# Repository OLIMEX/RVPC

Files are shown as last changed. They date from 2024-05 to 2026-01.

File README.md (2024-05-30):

# RVPC
The EURO 1.00 Risc-V personal computer with VGA and Keyboard and Woz like monitor. The purpose of this project is to make educational platform which people can use to learn RISCV assembler and experiment like in the old days in 1980s :)

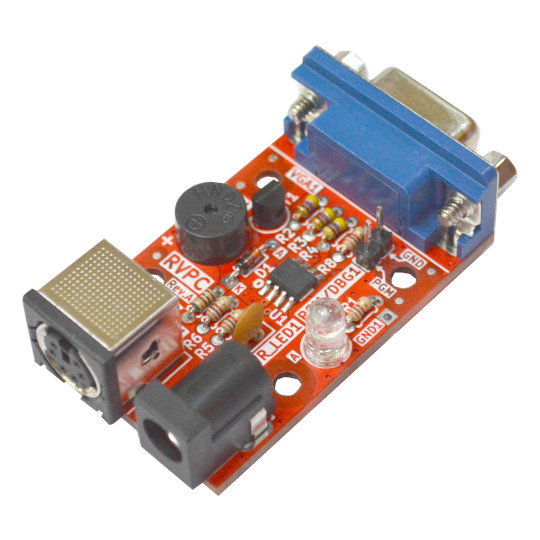
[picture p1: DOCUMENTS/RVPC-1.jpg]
RVPC-1


https://www.olimex.com/Products/Retro-Computers/RVPC/open-source-hardware

## Licensee
* Hardware is released under CERN Open Hardware Licence Version 2 - Strongly Reciprocal
* Software is released under GPL V3 Licensee
* Documentation is released under CC BY-SA 4.0

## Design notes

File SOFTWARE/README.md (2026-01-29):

# PlatformIO
The PlatformIO flder contains demo project which drive the beeper,
You can open and upload it and you will hear sound.

# Tools
The rvpc folder contains all the tools needed to program an ESP32-S2-DevKitLiPo-USB to act as a programmer, and minichlink, which uses the ESP32-S2 to program CH32V003.
Follow the instructions in the user manual.

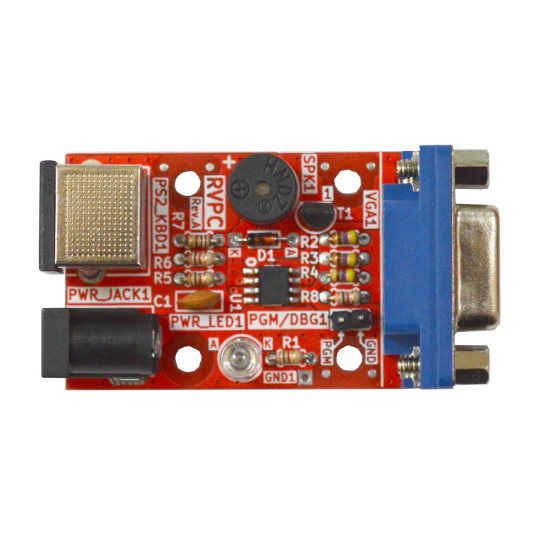
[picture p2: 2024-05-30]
DOCUMENTS/RVPC-2.jpg

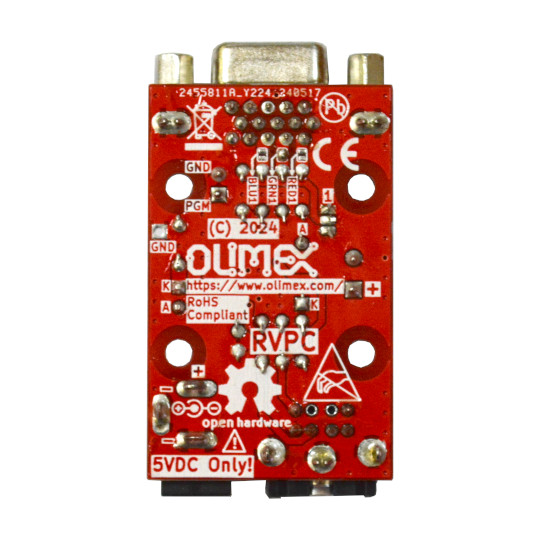
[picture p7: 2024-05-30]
DOCUMENTS/RVPC-3.jpg

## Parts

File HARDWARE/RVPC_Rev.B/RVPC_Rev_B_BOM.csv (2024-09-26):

Quantity | Value | Footprint | Reference
1 | 100nF/25V/2010 | C2010 | C1
1 | 1N4148/DO35 | DO35_1K_2A | D1
1 | HN1x2 | HN1x2 | PGM/DBG1
1 | MDR6_MINI-DIN | PS2_MDR6_MINI-DIN | PS2_KBD1
1 | PWRJ-2mm(YDJ-1134) | PWRJ-2mm(YDJ-1136) | PWR_JACK1
1 | LED/PTH/5MM/RED | LED-5mm-PTH-KA | PWR_LED1
4 | 2k/1/8W | R_0.125W_PTH | R1, R5, R6, R8
3 | 470R/1/8W | R_0.125W_PTH | R2, R3, R4
1 | 100R/1/8W | R_0.125W_PTH | R7
1 | Speaker_QMB-09B-03(1.5-5.0V_2.7kHz_F9.0mm*H5.5mm) | Speaker_QMB-09B-03_1-Plus_2-Minus | SPK1
1 | 2N3904 | TO-92_PTH | T1
1 | CH32V003J4M6(SOP8) | SOIC-8_150mil | U1
1 | HDR15-3.08-14.5T/VGA15/14.5mm | VGA15-F(HDR15-3.08-14.5T)_DrillSlot | VGA1

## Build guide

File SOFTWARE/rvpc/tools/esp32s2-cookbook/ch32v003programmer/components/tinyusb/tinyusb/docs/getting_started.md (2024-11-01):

# Getting Started #

## Add TinyUSB to your project

It is relatively simple to incorporate tinyusb to your (existing) project

- Copy or `git submodule` this repo into your project in a subfolder. Let's say it is *your_project/tinyusb*
- Add all the .c in the `tinyusb/src` folder to your project
- Add *your_project/tinyusb/src* to your include path. Also make sure your current include path also contains the configuration file tusb_config.h.
- Make sure all required macros are all defined properly in tusb_config.h (configure file in demo application is sufficient, but you need to add a few more such as CFG_TUSB_MCU, CFG_TUSB_OS since they are passed by IDE/compiler to maintain a unique configure for all boards).
- If you use the device stack, make sure you have created/modified usb descriptors for your own need. Ultimately you need to implement all **tud_descriptor_** callbacks for the stack to work.
- Add tusb_init() call to your reset initialization code.
- Call `tud_int_handler()` (device) and/or `tuh_int_handler()` (host) in your USB IRQ Handler
- Implement all enabled classes's callbacks.
- If you don't use any RTOSes at all, you need to continuously and/or periodically call tud_task()/tuh_task() function. All of the callbacks and functionality are handled and invoked within the call of that task runner.

~~~{.c}
int main(void)
{
  your_init_code();
  tusb_init(); // initialize tinyusb stack

  while(1) // the mainloop
  {
    your_application_code();

    tud_task(); // device task
    tuh_task(); // host task
  }
}
~~~

## Examples

For your convenience, TinyUSB contains a handful of examples for both host and device with/without RTOS to quickly test the functionality as well as demonstrate how API() should be used. Most examples will work on most of [the supported Boards](boards.md). Firstly we need to `git clone` if not already

```
$ git clone https://github.com/hathach/tinyusb tinyusb
$ cd tinyusb
```

Some TinyUSB examples also requires external submodule libraries in `/lib` such as FreeRTOS, Lightweight IP to build. Run following command to fetch them 

```
$ git submodule update --init lib
```

In addition, MCU driver submodule is also needed to provide low-level MCU peripheral's driver. Luckily, it will be fetched if needed when you run the `make` to build your board.

Note: some examples especially those that uses Vendor class (e.g webUSB) may requires udev permission on Linux (and/or macOS) to access usb device. It depends on your OS distro, typically copy `/examples/device/99-tinyusb.rules` file to /etc/udev/rules.d/ then run `sudo udevadm control --reload-rules && sudo udevadm trigger` is good enough.

### Build

To build example, first change directory to an example folder. 

```
$ cd examples/device/cdc_msc
```

Then compile with `make BOARD=[board_name] all`, for example

```
$ make BOARD=feather_nrf52840_express all
```

Note: `BOARD` can be found as directory name in `hw/bsp`, either in its family/boards or directly under bsp (no family).

#### Port Selection

If a board has several ports, one port is chosen by default in the individual board.mk file. Use option `PORT=x` To choose another port. For example to select the HS port of a STM32F746Disco board, use:

```
$ make BOARD=stm32f746disco PORT=1 all
```

#### Port Speed

A MCU can support multiple operational speed. By default, the example build system will use the fastest supported on the board. Use option `SPEED=full/high` e.g To force F723 operate at full instead of default high speed

```
$ make BOARD=stm32f746disco SPEED=full all
```

### Debug

To compile for debugging add `DEBUG=1`, for example

```
$ make BOARD=feather_nrf52840_express DEBUG=1 all
```

#### Log

Should you have an issue running example and/or submitting an bug report. You could enable TinyUSB built-in debug logging with optional `LOG=`. LOG=1 will only print out error message, LOG=2 print more information with on-going events. LOG=3 or higher is not used yet. 

```
$ make BOARD=feather_nrf52840_express LOG=2 all
```

#### Logger

By default log message is printed via on-board UART which is slow and take lots of CPU time comparing to USB speed. If your board support on-board/external debugger, it would be more efficient to use it for logging. There are 2 protocols: 

- `LOGGER=rtt`: use [Segger RTT protocol](https://www.segger.com/products/debug-probes/j-link/technology/about-real-time-transfer/)   
  - Cons: requires jlink as the debugger.
  - Pros: work with most if not all MCUs
  - Software viewer is JLink RTT Viewer/Client/Logger which is bundled with JLink driver package.
- `LOGGER=swo`: Use dedicated SWO pin of ARM Cortex SWD debug header.
  - Cons: only work with ARM Cortex MCUs minus M0
  - Pros: should be compatible with more debugger that support SWO.
  - Software viewer should be provided along with your debugger driver.

```
$ make BOARD=feather_nrf52840_express LOG=2 LOGGER=rtt all
$ make BOARD=feather_nrf52840_express LOG=2 LOGGER=swo all
```

### Flash

`flash` target will use the default on-board debugger (jlink/cmsisdap/stlink/dfu) to flash the binary, please install those support software in advance. Some board use bootloader/DFU via serial which is required to pass to make command

```
$ make BOARD=feather_nrf52840_express flash
$ make SERIAL=/dev/ttyACM0 BOARD=feather_nrf52840_express flash
```

Since jlink can be used with most of the boards, there is also `flash-jlink` target for your convenience.

```
$ make BOARD=feather_nrf52840_express flash-jlink
```

Some board use uf2 bootloader for drag & drop in to mass storage device, uf2 can be generated with `uf2` target

```
$ make BOARD=feather_nrf52840_express all uf2
```

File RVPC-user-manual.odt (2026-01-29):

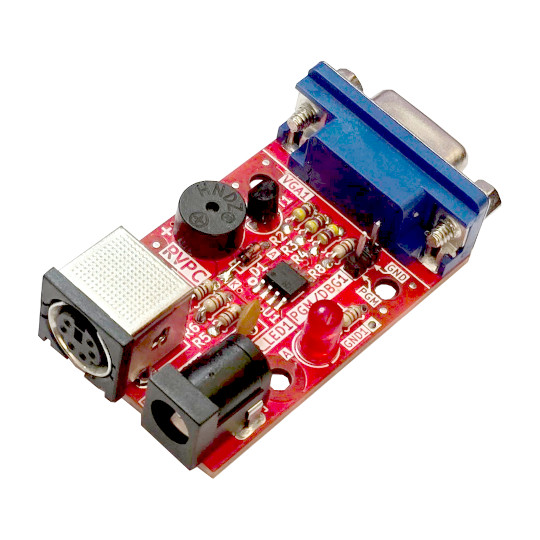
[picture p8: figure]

RVPC

User Manual

Document v1.3 Nov 2024

www. (http://www.olimex.com/)o (http://www.olimex.com/)limex.com (http://www.olimex.com/)

# What is RVPC?

RVPC is an attempt to produce a very low-cost EURO 1.00 educational computer with RISC-V processor which has everything one complete computer has: keyboard input, VGA display output, and audio output.

The idea of RVPC was born from this TuxCon 2024 talk https://youtu.be/YlYE9a7zsqY.

The goal set was:

1. Easy to solder DIY kit;
2. Complete all in one RISC-V computer with bare minimum Woz like monitor which will allow you to learn the RISC-V instructions by poking, peeking and disassembling the memory
3. Price of EUR 1.00!

Here is the result:

CH32V003 in SO8 package – for easy soldering was chosen. It has just 6 GPIOs:

- PS2 takes two GPIOs

- VGA takes three GPIOs – Vsync, Hsync and RGB

- Audio buzzer is connected to the last GPIO

All done using beginner-friendly PTH components!

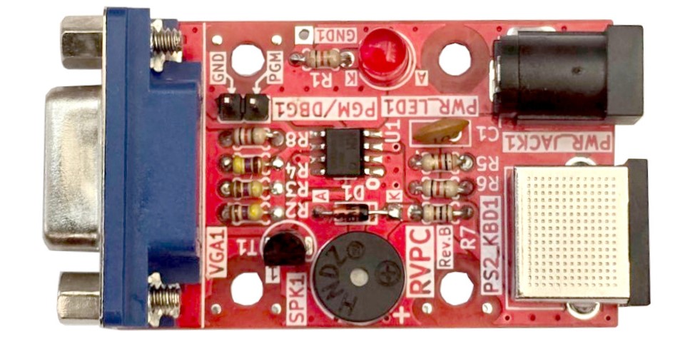
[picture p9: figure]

## Order codes for RVPC and accessories:

RVPC (https://www.olimex.com/Products/Retro-Computers/RVPC/open-source-hardware) Do It Yourself soldering kit

SY0605E (https://www.olimex.com/Products/Power/SY0605E-CHINA/) 5V power supply adapter

PS2-KEYBOARD (https://www.olimex.com/Products/Retro-Computers/PS2-KEYBOARD/) PS2 keyboard

E (https://www.olimex.com/Products/IoT/ESP32-S2/ESP32-S2-DevKit-Lipo-USB/open-source-hardware)SP32-S2-DevKitLiPo-USB (https://www.olimex.com/Products/IoT/ESP32-S2/ESP32-S2-DevKit-Lipo-USB/open-source-hardware) ESP32-S2 development board which can be used as CH32V003

programmer

USB-CABLE-A-MICRO-1.8M (https://www.olimex.com/Products/Components/Cables/USB-CABLE-A-MICRO-1.8M/) USB cable for the programmer

# HARDWARE

## RVPC layout:


PS2 keyboard connector

Buzzer

VGA display

+5V power

jack

Power supply LED indicator

CH32V003 programming

## RVPC schematic:

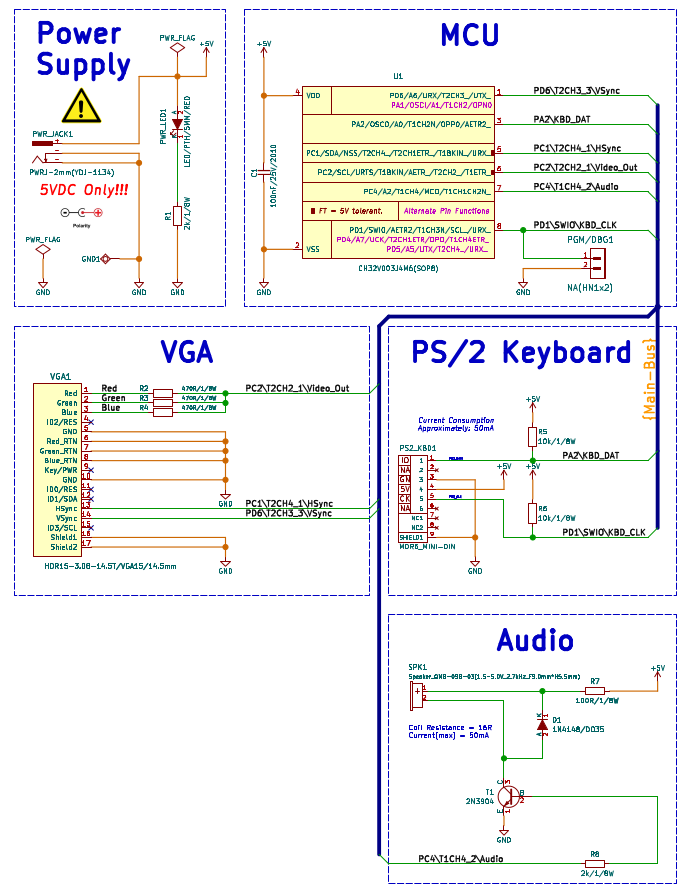
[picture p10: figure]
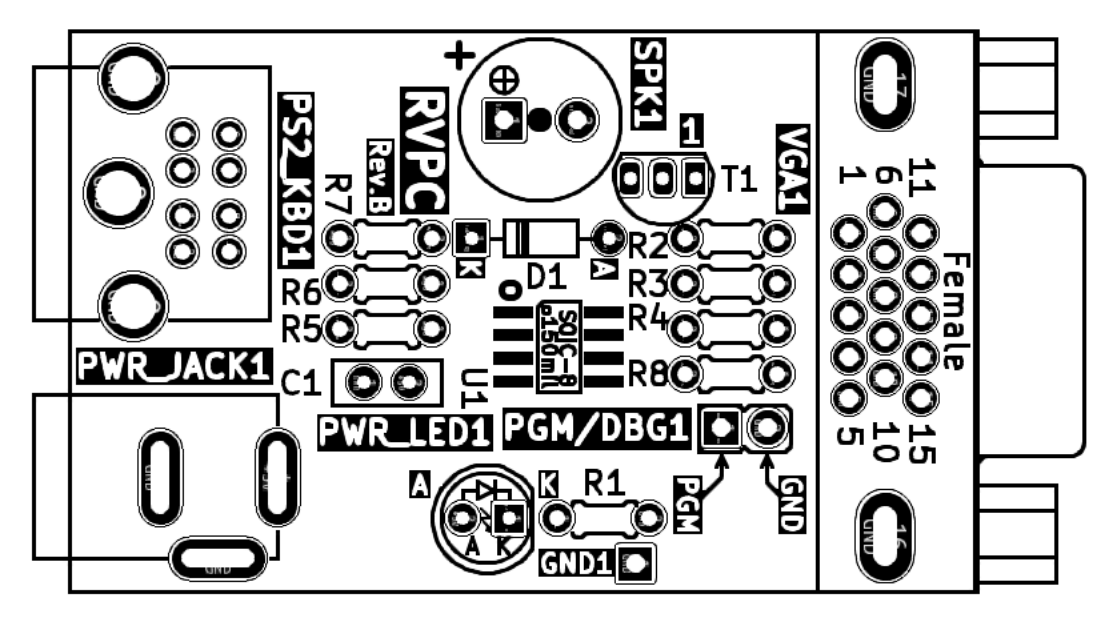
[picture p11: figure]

## RPVC assembly cheat sheet:

After assembly remember to close jumper GRN1 (solder together the pads of GRN1) to enable the green VGA signal.

## Necessary tools:

Wire Cutters: we recommend PGC-TR25 (https://www.olimex.com/Products/Tools/HandTools/PGC-TR25/) these are sharp and light

Tweezers: we recommend PGC-00SA (https://www.olimex.com/Products/Tools/HandTools/PGC-00SA/)

Soldering iron: CHN-SLD802 (https://www.olimex.com/Products/Tools/Soldering/CHN-SLD802/) is budged solution, SLD-FAST-75W (https://www.olimex.com/Products/Tools/Soldering/SLD-FAST-75W/) is professional solution

Soldering wire: we recommend Solder-Wire-SAC0307-0-8 (https://www.olimex.com/Products/Components/Soldering/Solder-Wire-SAC0307-0-8/)

## General tips for soldering:

1. Switch on the soldering iron, setup the working temperature to 350 C. Wait until the soldering iron reaches the temperature – there is a LED indicator which will pulse when the temperature is reached;

2. Before soldering, clean the soldering tip with wet sponge from the black residues;

3. Never touch the heated soldering tip or body with bare hands;

4. Be careful to not touch surrounding objects with the soldering iron heated body or tip (cables, table, cloths, etc);

5. Do not leave the soldering iron unattended;

6. Place the electronic component on its place, watch out if there is polarity or orientation;

7. Touch the component pad with the soldering tip which you want to solder and wait 3-4 seconds to heat up;

8. Feed a little from the soldering wire between the soldering tip and the pad until the component lead is flooded with tin and it’s shinny and glossy;

9. If the soldering is not shinny but dull please re-solder with colophon.

# SOFTWARE:

Below is our setup under Linux:

## Install – packages

$ apt-get install build-essential libnewlib-dev gcc-riscv64-unknown-elf libusb-1.0-0-dev libudev-dev gdb-multiarch

## Install – Visual Studio Code

Described here: https://code.visualstudio.com/docs/setup/linux

## Install – Platform IO

Described here: https://platformio.org/install/ide?install=vscode

## Install – CH32V-Platform

https://github.com/Community-PIO-CH32V/ch32-pio-projects?tab=readme-ov-file#installing-the-ch32v-platform

by default the platformio generates only .elf file, to build firmware.bin and firmware.elf select

> PlatformIO > PROJECT TASKS > Default > Advanced > Verbose build

Sample Beeper project is in RVPC repository.

## Prepare the CH32V003 programmer

ESP32-S2-DevKitLiPo-USB (https://www.olimex.com/Products/IoT/ESP32-S2/ESP32-S2-DevKit-Lipo-USB/open-source-hardware) can be used as programmer.

The repo with all files required to prepare the ESP32-S2 board as programmer is here (https://github.com/OLIMEX/RVPC/tree/main/SOFTWARE) – after you have the resources the algorithm to prepare the programmer is:

1. Press and hold the Boot button and connect the USB cable, the yellow LED will stay ON

check with

$ ls /dev/ttyA*

which is the ttyACM it’s usually 0 or 1

execute this command:

$ python3 ./rvpc/esptool/esptool.py -p /dev/ttyACM0 -b 460800 --before=no_reset --after=no_reset write_flash --flash_mode dio --flash_freq 80m --flash_size 4MB 0x1000 ./rvpc/esp32s2/bootloader.bin 0x10000 ./rvpc/esp32s2/usb_sandbox.bin 0x8000 ./rvpc/esp32s2/partition-table.bin

check if the programmer is already OK with

$ dmesg

you have to see this message:

hid-generic 0003:303A:4004.0015: input,hidraw5: USB HID v1.11 Gamepad [CNLohr ESP32-S2 CH32V003Programmer] on usb-0000:00:14.0-2/input0

which means the ESP32-S2-DevKitLipo-USB now acts as a programmer and can be used with the demo project above from PlatformIO, but first you have to enable it with:

$ sudo cp ./rvpc/tools/ch32v003fun/minichlink/99-minichlink.rules /etc/udev/rules.d/

$ sudo udevadm control --reload-rules && sudo udevadm trigger

Now you can use GPIO6 and GND to connect to RVPC programming connector PGM-GND

Now CH32V003 flashing will work directly from PlatformIO.

If you want to use command line this is the command:

./rvpc/tools/ch32v003fun/minichlink/minichlink -w ./firmware.bin 0x08000000

Notice that if you wish to use the command line programming you’d need to build the minichlink, install these libraries:

sudo apt-get install libudev-dev libusb-1.0-0-dev

then navigate to:

\rvpc\tools\ch32v003fun\minichlink and type make

## Using Raspberry Pi Pico as a programmer

Raspberry Pi Pico can be used as a programmer.

The programmer firmware is located here: https://github.com/aappleby/picorvd. Make sure you install the dependencies, especially GDB as you’ll need it for uploading the RVPC firmware later.

You can either build it yourself, or use a precompiled binary from their CI. The prebuilt binaries can be found in the Actions tab on the repository, selecting the most recent commit and scrolling to the bottom of the page where the Artifacts section is. There should be a single artifact named PicoRVD.uf2, which is the firmware build. If the downloaded file is a ZIP, make sure to unzip the firmware and discard the ZIP file.

Get your RPi Pico, hold down the BOOTSEL button and plug the USB cable into your computer. A new USB mass storage device should appear, copy the PicoRVD firmware file into it and wait for a moment. You don’t need to safely eject/remove it, since it will disconnect itself as soon as it receives the firmware file. It will then immediately boot the PicoRVD firmware and the Pico will be ready for flashing your RVPC.

RVPC firmware uploading is done by the Remote debugging feature of GDB. In order to automate it, you can use the following shell script:

#!/bin/bash

set -e

if [ -z "${1}" ]
then
echo 'usage: '"${0}" path/to/firmware.elf >&2
exit 1
fi

gdb-multiarch -ex 'target extended-remote /dev/ttyACM0' -ex 'load' -ex 'detach' -ex 'quit' "${1}"

To upload a new RVPC firmware, you need the .elf file, not the .bin file as GDB does not have enough information how to upload it. Before uploading a new firmware, restart your RVPC by power cycling it, then power-cycle your Pico and in case it appears as mass storage device, upload the PicoRVD firmware again. Then use the shell script, adjusting the /dev/ttyACM0 port according to the actual serial port name (you can find it in dmesg). After successfully uploading a new RVPC firmware, you need to power-cycle the RVPC, in order to start the program.

## Create project:

If you create a new project to enable the ESP32-S2 programmer you should edit platformio.ini and add this line

upload_protocol = minichlink

This is not needed for demo projects, since it’s already added to the demo projects at our GitHub.

## RVPC monitor demo RVMON (default)

The chip of RVPC comes programmed with this RVPC monitor demo. All demos can be found here:

https://github.com/OLIMEX/RVPC/tree/main/SOFTWARE

This is WOZ-like monitor which allow you to display memory, write to memory and execute code.

The list of all commands are displayed with “?”

## Towers of Hanoi demo

This is original game created by Curtis Whitley who wrote the VGA display code for RVPC.

## Towers of Hanoi Interactive demo

This is modified version which uses the keyboard so user can tell which disk to which tower go.

## TETRIS demo

This is the very popular game made for RVPC.

# Revision History

Revision 1.0 June 2024

Revision 1.1 September 2024

Revision 1.2 October 2024 add assembly instructions

Revision 1.3 November 2024 improved instructions

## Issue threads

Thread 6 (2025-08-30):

No success to get PS/2 Keyboards working

RoSchmi, 2025-08-30:
Thanks for this amazing project.
I soldered the board and get the expected screen output on my monitor. However I had no success to enter commands to the monitor. I tried different PS/2 keyboards and USB-Keyboards with PS/2 adapter with no success. The only reaction is some disturbance of the screen picture when I type a character. Are there any known issues or measures that have to be taken?
Kind regards
Roland

RoSchmi, 2025-08-30:
Turned out to be a soldering problem. It's working now.

Closed 2025-08-31.

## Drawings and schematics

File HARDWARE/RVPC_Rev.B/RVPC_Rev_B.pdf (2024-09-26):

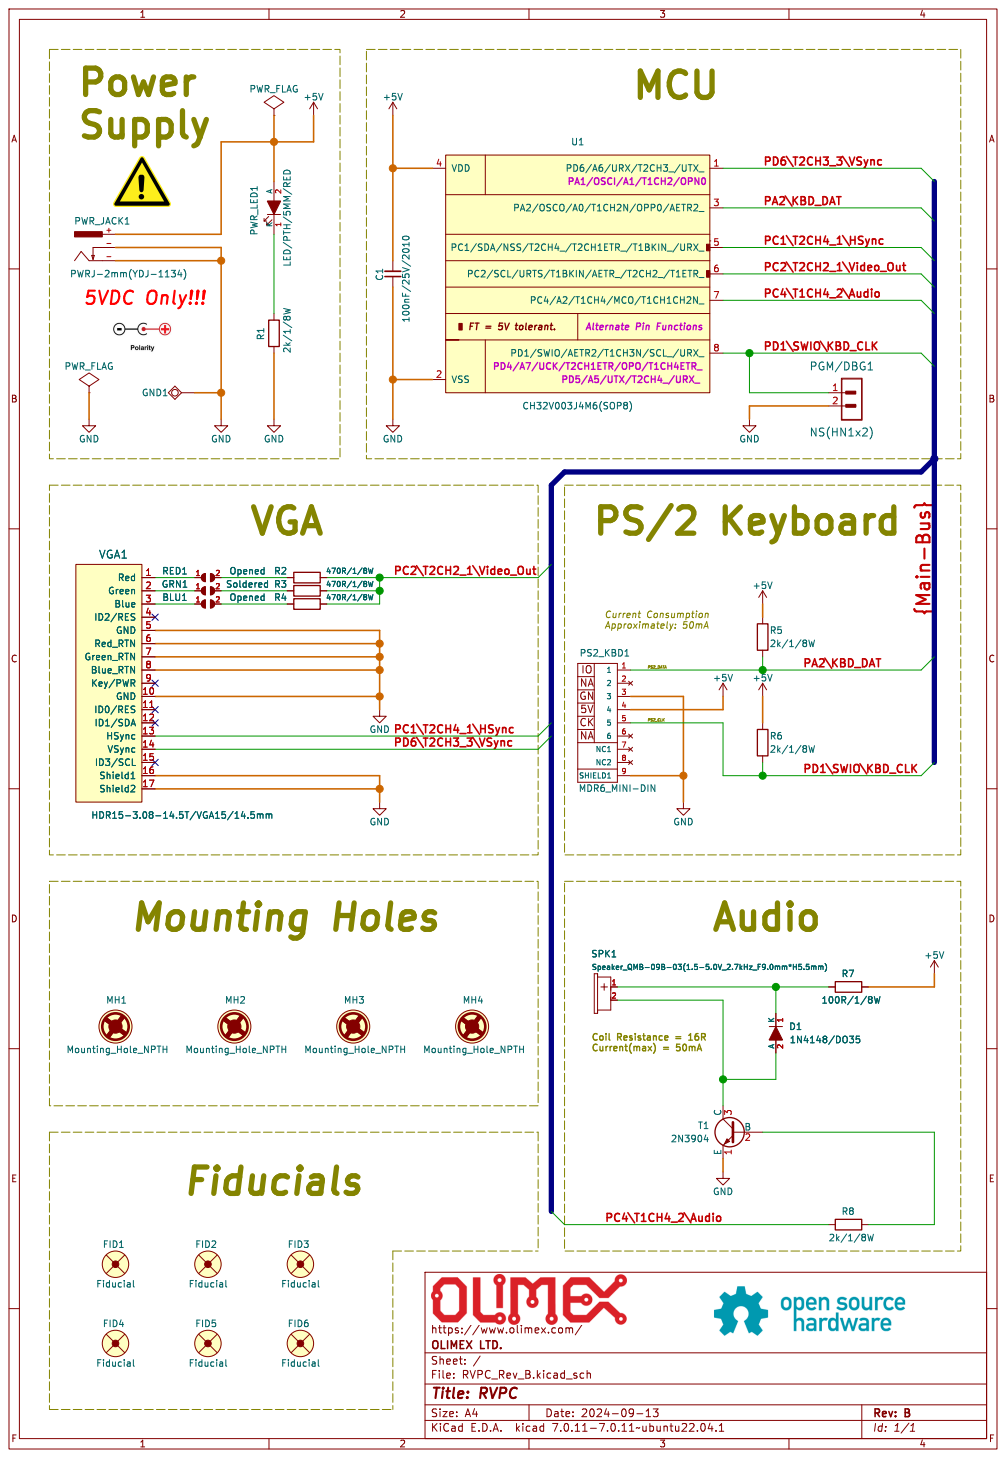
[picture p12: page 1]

2 PWR_LED1 LED/PTH/5MM/RED GND R1 2k/1/8W

PD1\SWIO\KBD_CLK {Main-Bus}VGA

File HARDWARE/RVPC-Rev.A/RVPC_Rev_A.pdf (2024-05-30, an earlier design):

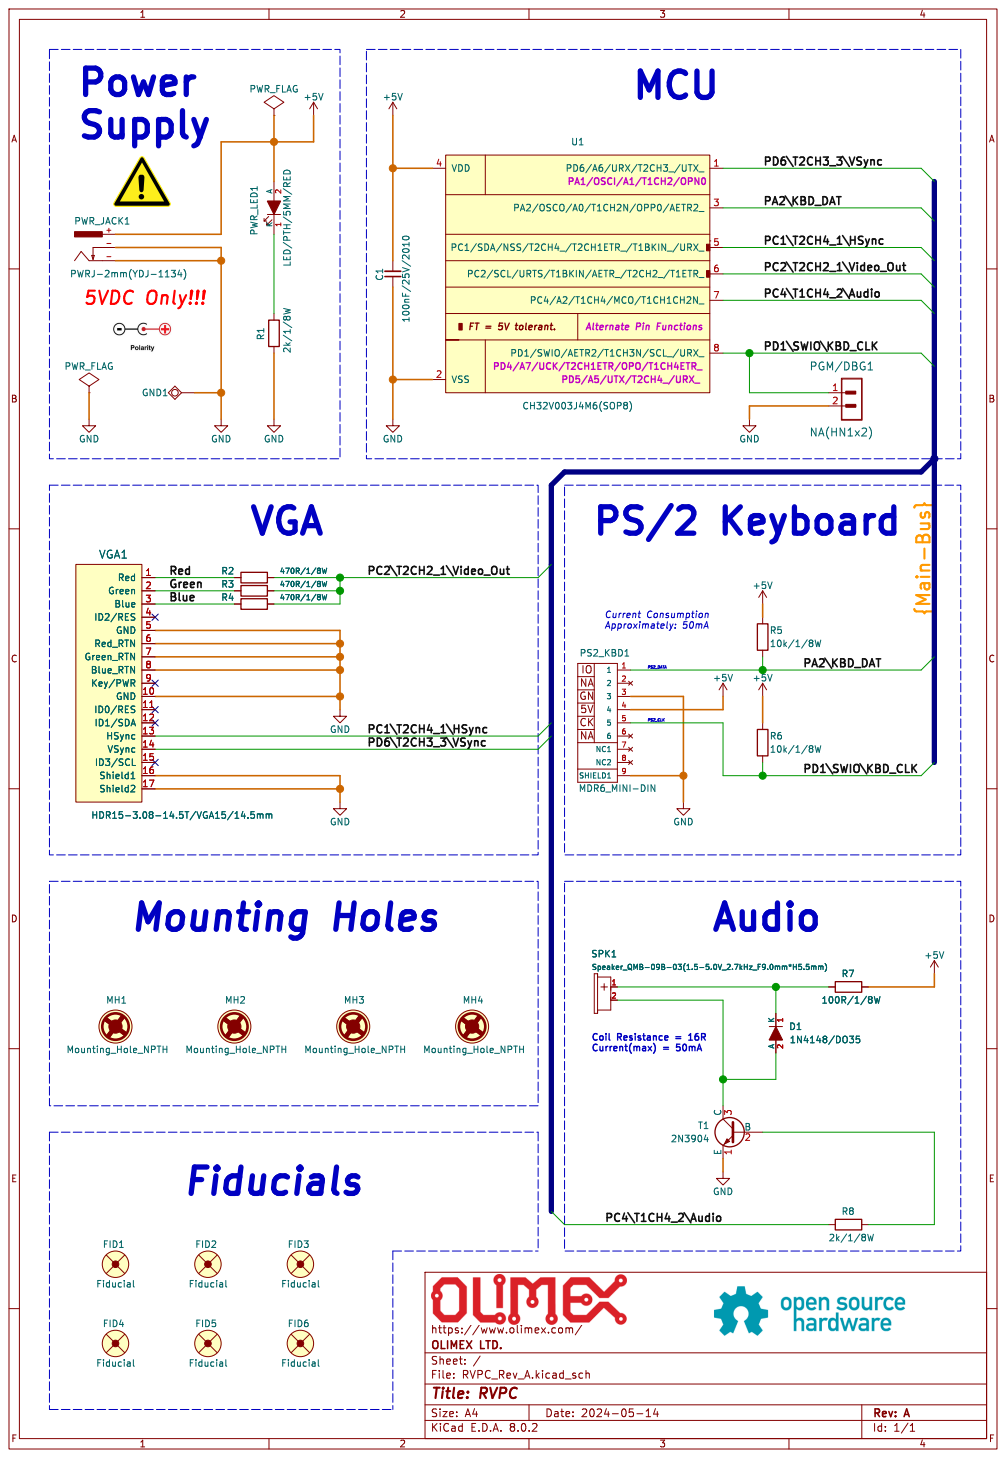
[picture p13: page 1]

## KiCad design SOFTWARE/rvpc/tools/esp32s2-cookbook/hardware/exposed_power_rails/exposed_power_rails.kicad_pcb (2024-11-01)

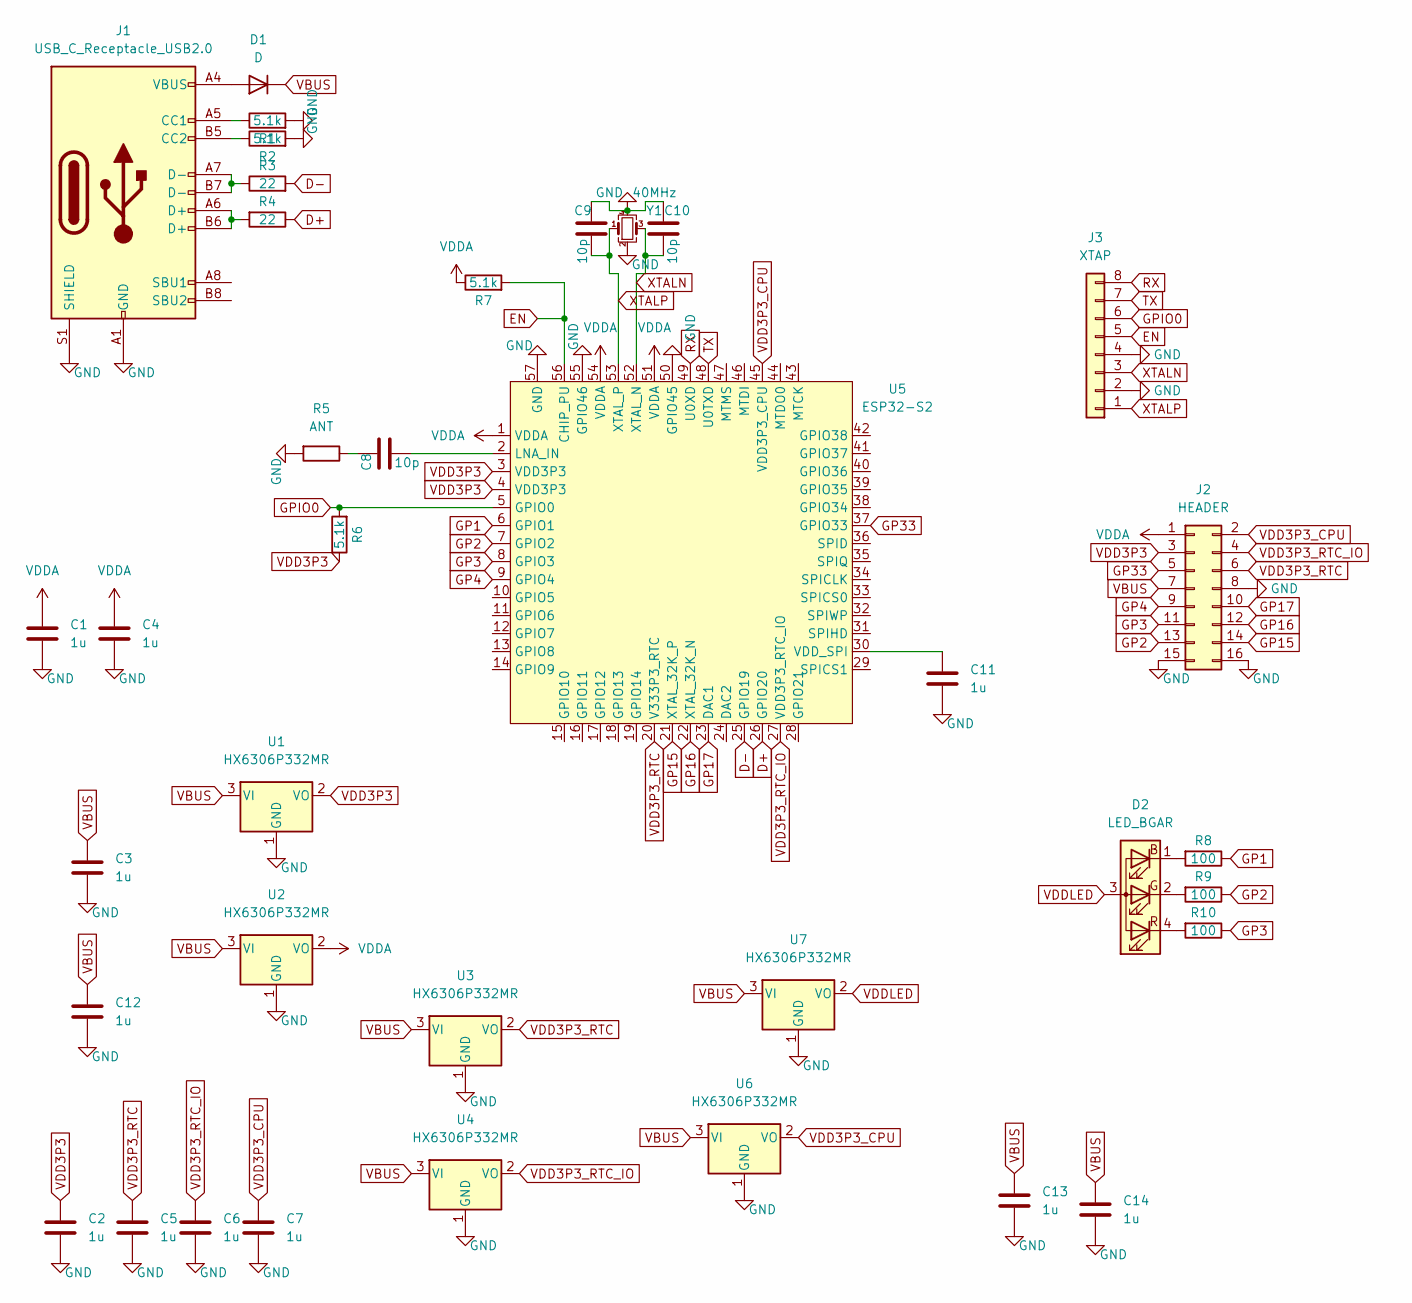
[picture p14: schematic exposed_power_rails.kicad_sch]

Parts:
C1, C2, C3, C4, C5, C6, C7, C11, C12, C13, C14: 1u; C_0201_0603Metric; LCSC C295898
C8, C9, C10: 10p; C_0201_0603Metric; LCSC C161369
D1: D; D_SOD-123F; LCSC C426570
D2: LED_BGAR; LED_Cree-PLCC4_2x2mm_CW; LCSC C2874116
J1: USB_C_Receptacle_USB2.0; USB_C_Receptacle_HRO_TYPE-C-31-M-12; LCSC C2765186
J2: HEADER; PinHeader_2x08_P2.54mm_Vertical; LCSC C492425
J3: XTAP; PinHeader_1x08_P2.54mm_Vertical; LCSC C2894931
R1, R2, R6, R7: 5.1k; R_0201_0603Metric; LCSC C473460
R3, R4: 22; R_0201_0603Metric; LCSC C144010
R5: ANT; Texas_SWRA117D_2.4GHz_Left
R8, R9, R10: 100; R_0201_0603Metric; LCSC C77623
U1, U2, U3, U4, U6, U7: HX6306P332MR; SOT-23; LCSC C296211
U5: ESP32-S2; ESP32S2; LCSC C2840995
Y1: 40MHz; Crystal_SMD_2016-4Pin_2.0x1.6mm; LCSC C648970

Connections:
D+: R4.1, U5.26 (GPIO20)
D-: R3.2, U5.25 (GPIO19)
EN: J3.5, R7.2, U5.56 (CHIP_PU)
GND: C1.2, C2.2, C3.2, C4.2, C5.2, C6.2, C7.2, C9.1, C10.1, C11.2, C12.2, C13.2, C14.2, J1.A1 (GND), J1.A12 (GND), J1.B1 (GND), J1.B12 (GND), J1.S1 (SHIELD), J2.8, J2.15, J2.16, J3.2, J3.4, R1.2, R2.2, R5.2, U1.1 (GND), U2.1 (GND), U3.1 (GND), U4.1 (GND), U5.50 (GPIO45), U5.55 (GPIO46), U5.57 (GND), U6.1 (GND), U7.1 (GND), Y1.2, Y1.4
GP1: R8.1, U5.6 (GPIO1)
GP2: J2.13, R9.1, U5.7 (GPIO2)
GP3: J2.11, R10.1, U5.8 (GPIO3)
GP4: J2.9, U5.9 (GPIO4)
GP15: J2.14, U5.21 (XTAL_32K_P)
GP16: J2.12, U5.22 (XTAL_32K_N)
GP17: J2.10, U5.23 (DAC1)
GP33: J2.5, U5.37 (GPIO33)
GPIO0: J3.6, R6.2, U5.5 (GPIO0)
unnamed: C8.1, R5.1
unnamed: C8.2, U5.2 (LNA_IN)
unnamed: C11.1, U5.30 (VDD_SPI)
unnamed: D1.2 (A), J1.A4 (VBUS), J1.A9 (VBUS), J1.B4 (VBUS), J1.B9 (VBUS)
unnamed: D2.1 (BK), R8.2
unnamed: D2.2 (GK), R9.2
unnamed: D2.4 (RK), R10.2
unnamed: J1.A5 (CC1), R1.1
unnamed: J1.A6 (D+), J1.B6 (D+), R4.2
unnamed: J1.A7 (D-), J1.B7 (D-), R3.1
unnamed: J1.B5 (CC2), R2.1
RX: J3.8, U5.49 (U0XD)
TX: J3.7, U5.48 (U0TXD)
VBUS: C3.1, C12.1, C13.1, C14.1, D1.1 (K), J2.7, U1.3 (VI), U2.3 (VI), U3.3 (VI), U4.3 (VI), U6.3 (VI), U7.3 (VI)
VDD3P3: C2.1, J2.3, R6.1, U1.2 (VO), U5.3 (VDD3P3), U5.4 (VDD3P3)
VDD3P3_CPU: C7.1, J2.2, U5.45 (VDD3P3_CPU), U6.2 (VO)
VDD3P3_RTC: C5.1, J2.6, U3.2 (VO), U5.20 (V333P3_RTC)
VDD3P3_RTC_IO: C6.1, J2.4, U4.2 (VO), U5.27 (VDD3P3_RTC_IO)
VDDA: C1.1, C4.1, J2.1, R7.1, U2.2 (VO), U5.1 (VDDA), U5.51 (VDDA), U5.54 (VDDA)
VDDLED: D2.3 (A), U7.2 (VO)
XTALN: C10.2, J3.3, U5.52 (XTAL_N), Y1.3
XTALP: C9.2, J3.1, U5.53 (XTAL_P), Y1.1

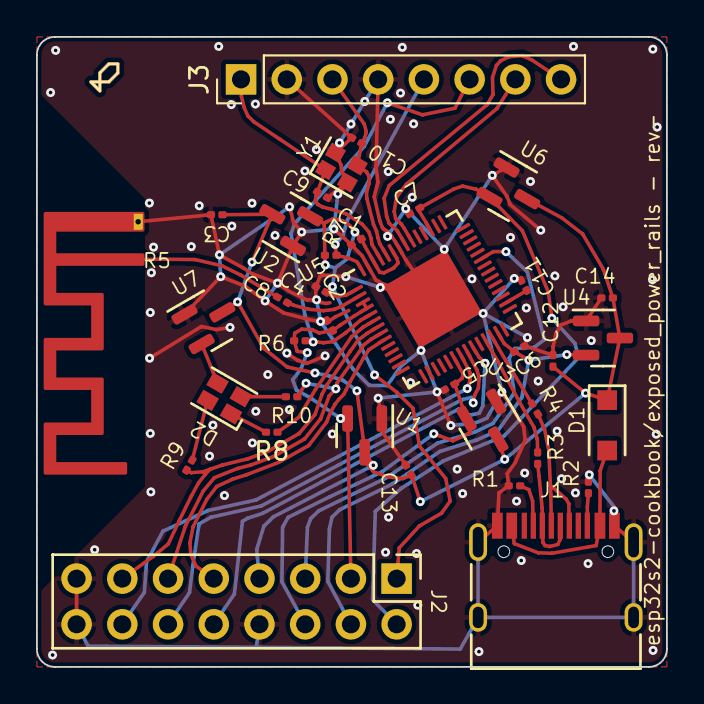
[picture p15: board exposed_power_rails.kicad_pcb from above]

Board: 2 copper layers, 35.0 x 35.0 mm, 37 parts (0 on the bottom side), 35 nets.

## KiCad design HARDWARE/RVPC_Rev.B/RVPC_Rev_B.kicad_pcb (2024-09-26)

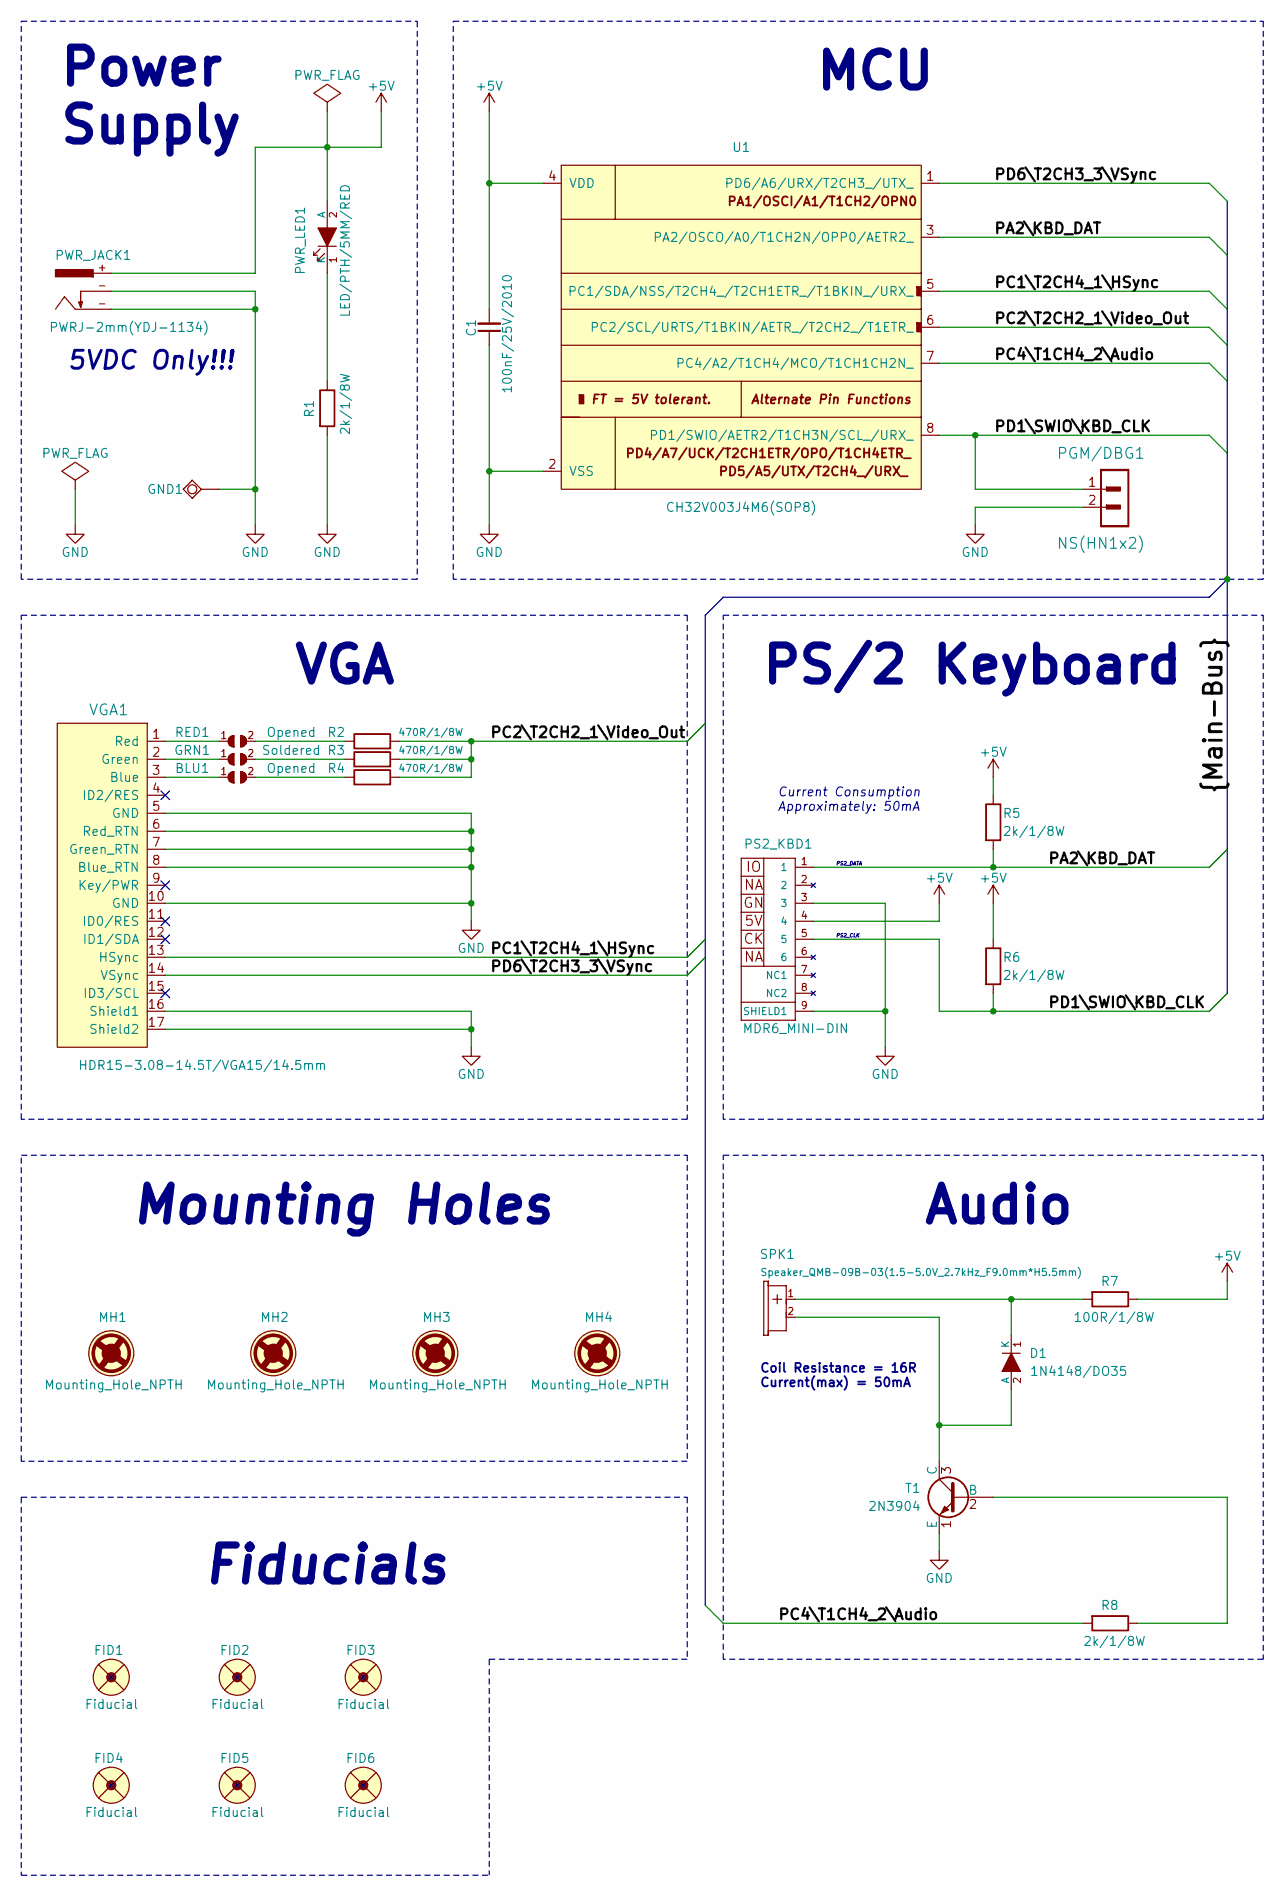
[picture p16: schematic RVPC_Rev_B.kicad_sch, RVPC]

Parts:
BLU1: Opened; SJ_1_SMALLER
C1: 100nF/25V/2010; C2010
D1: 1N4148/DO35; DO35_1K_2A
FID1, FID2, FID3: Fiducial; Fiducial1x3
FID4, FID5, FID6: Fiducial; Fiducial1x3_Paste
GND1: TESTPAD; TEST_PAD40x70_SQUARE
GRN1: Soldered; SJ_1_SMALLER
MH1, MH2, MH3, MH4: Mounting_Hole_NPTH; Mounting_Hole_Drill-3.3mm_Clerance-7mm
PGM/DBG1: NS(HN1x2); HN1x2
PS2_KBD1: MDR6_MINI-DIN; PS2_MDR6_MINI-DIN
PWR_JACK1: PWRJ-2mm(YDJ-1134); PWRJ-2mm(YDJ-1136)
PWR_LED1: LED/PTH/5MM/RED; LED-5mm-PTH-KA
R1, R5, R6, R8: 2k/1/8W; R_0.125W_PTH
R2, R3, R4: 470R/1/8W; R_0.125W_PTH
R7: 100R/1/8W; R_0.125W_PTH
RED1: Opened; SJ_1_SMALLER
SPK1: Speaker_QMB-09B-03(1.5-5.0V_2.7kHz_F9.0mm*H5.5mm); Speaker_QMB-09B-03_1-Plus_2-Minus
T1: 2N3904; TO-92_PTH
U1: CH32V003J4M6(SOP8); SOIC-8_150mil
VGA1: HDR15-3.08-14.5T/VGA15/14.5mm; VGA15-F(HDR15-3.08-14.5T)_DrillSlot

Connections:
+5V: C1.2, PS2_KBD1.4, PWR_JACK1.+, PWR_LED1.2 (A), R5.1, R6.1, R7.1, U1.4 (VDD)
/PA2\KBD_DAT: PS2_KBD1.1, R5.2, U1.3 (PA2/OSCO/A0/T1CH2N/OPP0/AETR2_)
/PC1\T2CH4_1\HSync: U1.5 (PC1/SDA/NSS/T2CH4_/T2CH1ETR_/T1BKIN_/UR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), VGA1.13 (HSync)
/PC2\T2CH2_1\Video_Out: R2.2, R3.2, R4.2, U1.6 (PC2/SCL/URTS/T1BKIN/AETR_/T2CH2_/T1ETR_)
/PC4\T1CH4_2\Audio: R8.2, U1.7 (PC4/A2/T1CH4/MCO/T1CH1CH2N_)
/PD1\SWIO\KBD_CLK: PGM/DBG1.1, PS2_KBD1.5, R6.2, U1.8 (PD1/SWIO/AETR2/T1CH3N/SCL_/URX_)
/PD6\T2CH3_3\VSync: U1.1 (PD6/A6/URX/T2CH3_/UTX_), VGA1.14 (VSync)
GND: C1.1, GND1.1 (Pad), PGM/DBG1.2, PS2_KBD1.3, PS2_KBD1.9 (SHIELD1), PWR_JACK1.-, R1.2, T1.1 (E), U1.2 (VSS), VGA1.5 (GND), VGA1.6 (Red_RTN), VGA1.7 (Green_RTN), VGA1.8 (Blue_RTN), VGA1.10 (GND), VGA1.16 (Shield1), VGA1.17 (Shield2)
unnamed: BLU1.2, R4.1
unnamed: D1.2 (A), SPK1.2 (MINUS), T1.3 (C)
unnamed: D1.1 (K), R7.2, SPK1.1 (PLUS)
unnamed: GRN1.2, R3.1
unnamed: PWR_LED1.1 (K), R1.1
unnamed: R2.1, RED1.2
unnamed: R8.1, T1.2 (B)
unnamed: BLU1.1, VGA1.3 (Blue)
unnamed: GRN1.1, VGA1.2 (Green)
unnamed: RED1.1, VGA1.1 (Red)

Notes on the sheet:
Power Supply
5VDC Only!!!
Mounting Holes
PS/2 Keyboard
PS2_CLK
Current Consumption Approximately: 50mA
MCU
PS2_DATA
VGA
Fiducials
Audio
Coil Resistance = 16R Current(max) = 50mA

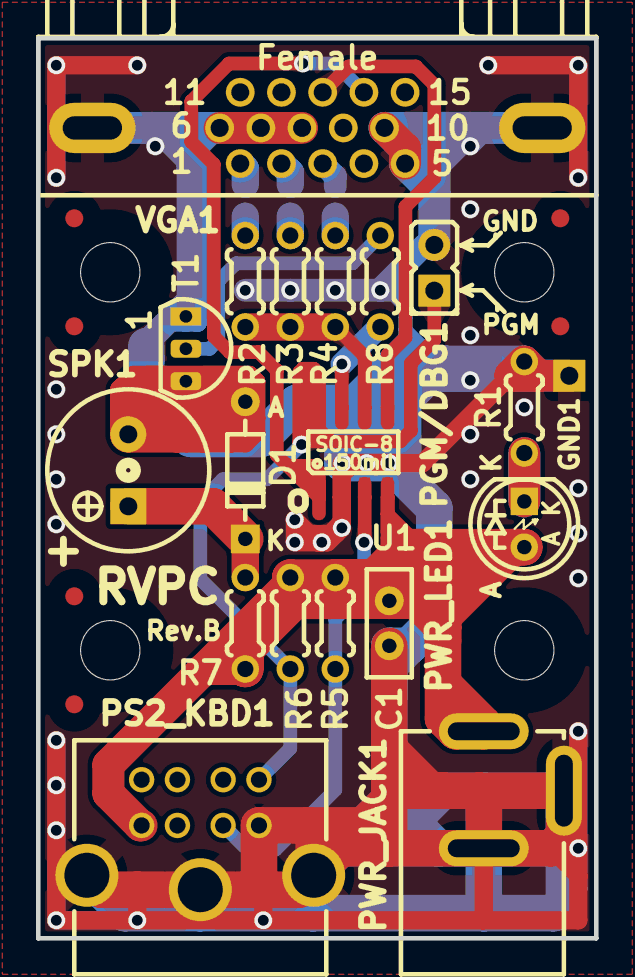
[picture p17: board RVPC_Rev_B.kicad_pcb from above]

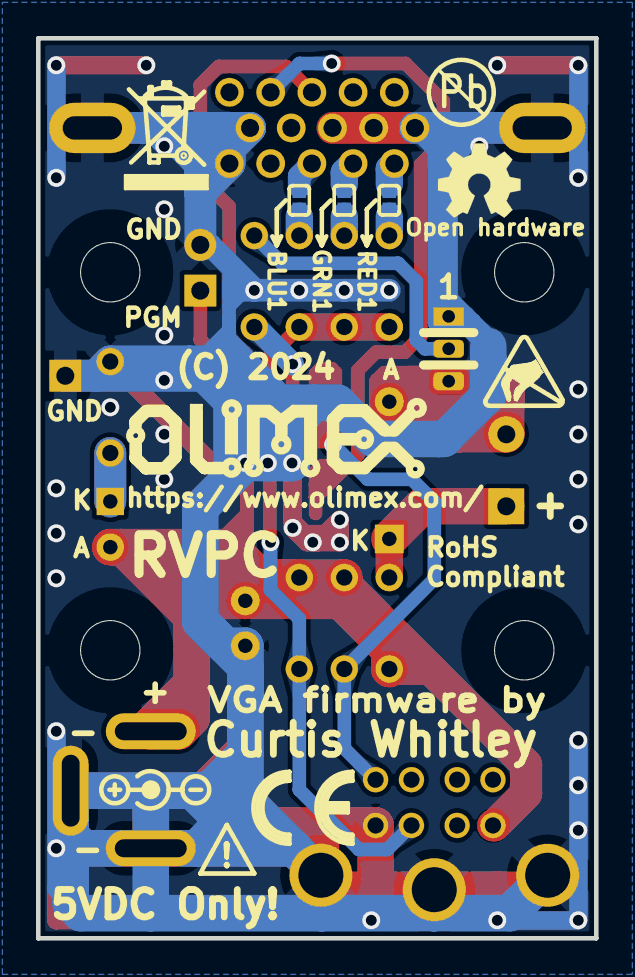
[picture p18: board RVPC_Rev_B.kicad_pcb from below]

Board: 2 copper layers, 31.0 x 50.0 mm, 38 parts (9 on the bottom side), 18 nets.

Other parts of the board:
Logo_OLIMEX_TB: Logo_OLIMEX_TB
Sign_Antistatic_Small: Sign_Antistatic; Sign_Antistatic_4.5mmX2.8mm
Sign_CE: CE_Sign
Sign_OSHW_7.3x6.0mm: Sign_OSHW_7.3x6.0mm; Sign_OSHW_7.3x6.0mmn
Sign_PB-Free: Sign_PB-Free
Sign_RecycleBin_1: Sign_RecycleBin_1

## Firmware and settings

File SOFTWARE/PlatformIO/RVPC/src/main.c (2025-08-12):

#include <ch32v00x.h>
#include <debug.h>

void NMI_Handler(void)       __attribute__((interrupt("WCH-Interrupt-fast")));
void HardFault_Handler(void) __attribute__((interrupt("WCH-Interrupt-fast")));

#define BUZZER_DELAY_MS 1

int main(void) {
	NVIC_PriorityGroupConfig(NVIC_PriorityGroup_1);
	SystemCoreClockUpdate();
    
    Delay_Init();

	// GPIO configuration
	RCC_APB2PeriphClockCmd(RCC_APB2Periph_GPIOC, ENABLE);

	GPIO_InitTypeDef cfg = {0};
    cfg.GPIO_Mode = GPIO_Mode_Out_PP;
   	cfg.GPIO_Pin = GPIO_Pin_4;
	cfg.GPIO_Speed = GPIO_Speed_10MHz;
    GPIO_Init(GPIOC, &cfg);

	while (1) {
		GPIO_WriteBit(GPIOC, GPIO_Pin_4, 1);
		Delay_Ms(BUZZER_DELAY_MS);
		GPIO_WriteBit(GPIOC, GPIO_Pin_4, 0);
		Delay_Ms(BUZZER_DELAY_MS);
	}

}

void NMI_Handler(void) {
	
}

void HardFault_Handler(void) {
	
	while (1) {
		
	}
}

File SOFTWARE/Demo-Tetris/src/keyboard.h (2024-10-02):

/**
 * This file is part of the RVPC project 
 * https://github.com/OLIMEX/RVPC
 * https://www.olimex.com/Products/Retro-Computers/RVPC/open-source-hardware
 * 
 * Copyright (c) 2024 Olimex Ltd
 * 
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
 * You should have received a copy of the GNU General Public License 
 * along with this program. If not, see <http://www.gnu.org/licenses/>.
 */

#ifndef __KEYBOARD_H
#define __KEYBOARD_H

#include <ch32v00x.h>

#define KBD_USE_BUZZ

#define KBD_PERIPHERY     (RCC_APB2Periph_GPIOA | RCC_APB2Periph_GPIOC | RCC_APB2Periph_GPIOD)
#define KBD_CLOCK_PORT    GPIOD
#define KBD_CLOCK_PIN     GPIO_Pin_1

#define KBD_INT_PORT_SRC  GPIO_PortSourceGPIOD
#define KBD_INT_PIN_SRC   GPIO_PinSource1
#define KBD_INT_LINE      EXTI_Line1

#define KBD_DATA_PORT     GPIOA
#define KBD_DATA_PIN      GPIO_Pin_2

#define BUZZ_PORT         GPIOC
#define BUZZ_PIN          GPIO_Pin_4

void buzz(uint32_t hz, uint32_t timeMS);
void buzz_ok();

void kbd_init();
uint32_t kbd_read();

uint32_t kbd_wait();
uint32_t kbd_wait_press();
uint32_t kbd_wait_release();
char kbd_to_ascii(uint32_t key_code);

#endif // __KEYBOARD_H

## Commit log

2024-05-30 initial upload schematic and CAD files
    [RVPC_Rev_A.kicad_pcb, RVPC_Rev_A.kicad_sch]
2024-09-26 update demo code
    [RVPC_Rev_B-B_Cu.gbr, RVPC_Rev_B-B_Mask.gbr, RVPC_Rev_B-B_Paste.gbr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]
2024-10-31 update assembly instructions
2024-11-01 Added sources
    [exposed_power_rails.kicad_pcb, exposed_power_rails.kicad_sch, partitions.csv]

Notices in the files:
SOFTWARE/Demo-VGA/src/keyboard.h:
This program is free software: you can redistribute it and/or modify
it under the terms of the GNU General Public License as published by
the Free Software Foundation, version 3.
